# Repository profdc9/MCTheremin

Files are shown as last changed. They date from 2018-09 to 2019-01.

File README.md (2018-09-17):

This is a theremin based on the "Bluepill" devboard with a STM32F103C8T6 microcontroller.
This material is copyrighted by Daniel Marks (KW4TI) and licensed under
the Creative Commons License CC-BY-SA 4.0.  Software is copyrighted using the zlib
open-source license.

It consists of three parts: 

MCTheremin directory - the stm32duino project

board - the PCB board in Kicad of the theremin.

genwaves - little octave script to generate the waveform data

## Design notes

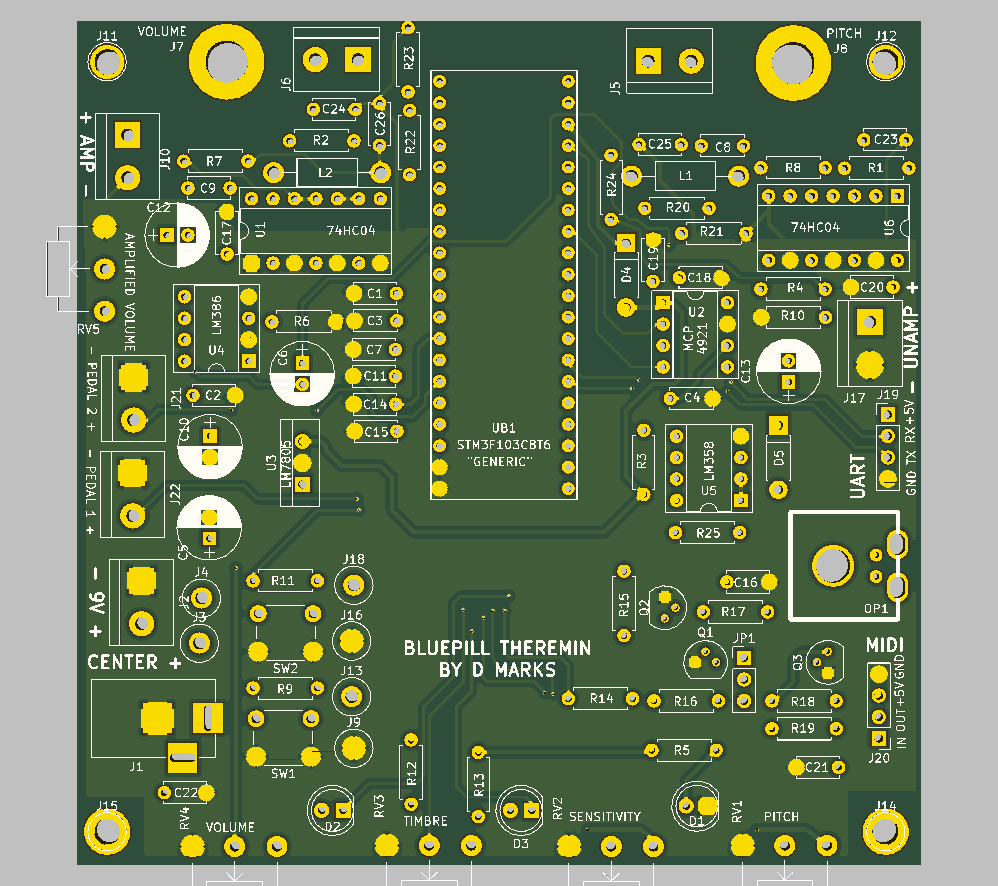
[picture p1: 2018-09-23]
board/MCTheremin.png

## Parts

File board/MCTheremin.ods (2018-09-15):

 | MCTheremin BOM
 | 86
C1 | 100 nF ceramic disc capacitor
C2 | 100 nF ceramic disc capacitor
C3 | 100 nF ceramic disc capacitor
C4 | 100 nF ceramic disc capacitor
C5 | 100 uF ceramic disc capacitor
C6 | 10 uF radial electrolytic capacitor
C7 | 100 nF ceramic disc capacitor
C8 | 33 pF ceramic disc capacitor
C9 | 68 pF ceramic disc capacitor
C10 | 100 uF radial electrolytic capacitor
C11 | 100 nF ceramic disc capacitor
C12 | 220 uF radial electrolytic capacitor
C13 | 220 uF radial electrolytic capacitor
C14 | 100 nF ceramic disc capacitor
C15 | 100 nF ceramic disc capacitor
C16 | 100 nF ceramic disc capacitor
C17 | 100 nF ceramic disc capacitor
C18 | 100 nF ceramic disc capacitor
C19 | 100 nF ceramic disc capacitor
D1 | 3 mm LED
D2 | 3 mm LED
D3 | 3 mm LED
D4 | 1N5819
D5 | 1N5819
J1 | Barrel_Jack
J2 | 2 position terminal block
J3 | Conn_01x01
J4 | Conn_01x01
J5 | 2 position terminal block
J6 | 2 position terminal block
J7 | Conn_01x01
J8 | Conn_01x01
J9 | Conn_01x01
J10 | 2 position terminal block
J11 | Conn_01x01
J12 | Conn_01x01
J13 | Conn_01x01
J14 | Conn_01x01
J15 | Conn_01x01
J16 | Conn_01x01
J17 | 2 position terminal block
J18 | Conn_01x01
J19 | 4 pin 2.54 mm spacing header
J20 | 4 pin 2.54 mm spacing header
J21 | 2 position terminal block
J22 | 2 position terminal block
JP1 | 3 pin 2.54 mm spacing header
OP1 | IFE97
Q1 | 2N3904
Q2 | 2N3904
Q3 | 2N3904
R1 | 10k ¼ watt resistor
R2 | 10k ¼ watt resistor
R3 | 100k ¼ watt resistor
R5 | 1k ¼ watt resistor
R6 | 10k ¼ watt resistor
R7 | 10k ¼ watt resistor
R8 | 10k ¼ watt resistor
R9 | 10k ¼ watt resistor
R10 | 10k ¼ watt resistor
R11 | 10k ¼ watt resistor
R12 | 1k ¼ watt resistor
R13 | 1k ¼ watt resistor
R14 | 1k ¼ watt resistor
R15 | 1k ¼ watt resistor
R16 | 10k ¼ watt resistor
R17 | 100R ¼ watt resistor
R18 | 220R ¼ watt resistor
R19 | 220R ¼ watt resistor
R20 | 1k ¼ watt resistor
R21 | 1.8k ¼ watt resistor
R22 | 1k ¼ watt resistor
R23 | 1.8k ¼ watt resistor
RV1 | 10k ¼ watt resistor
RV2 | 10k ¼ watt resistor
RV3 | 10k ¼ watt resistor
RV4 | 10k ¼ watt resistor
RV5 | 10k ¼ watt resistor
SW1 | 6 mm PCB pushbutton normally open
SW2 | 6 mm PCB pushbutton normally open
U1 | 74HC04 DIP-14 package
U2 | MCP4921 DIP-8 package
U3 | LM7805 TO-220
U4 | LM386 DIP-8 package
U5 | LM358 DIP-8 package
UB1 | BLUEPILL STM32F103C8T6 board (two header sockets)

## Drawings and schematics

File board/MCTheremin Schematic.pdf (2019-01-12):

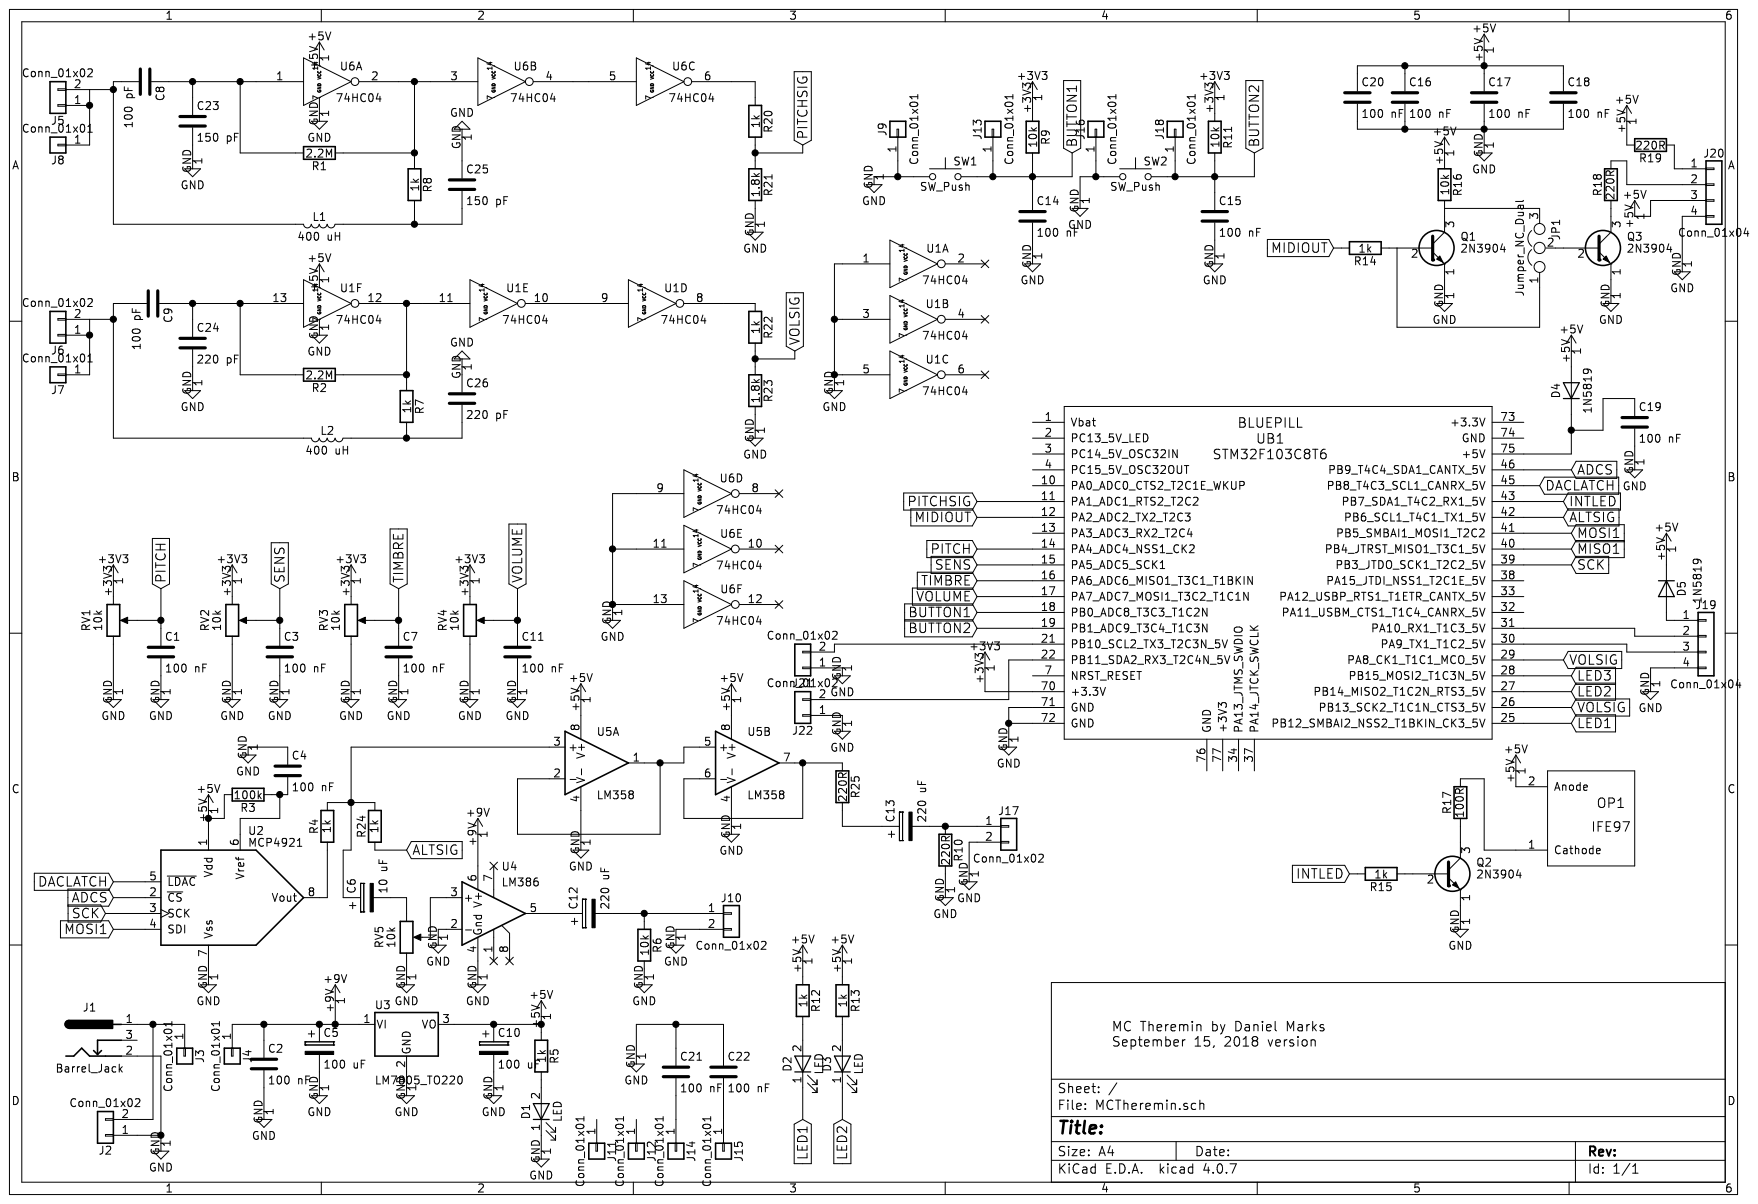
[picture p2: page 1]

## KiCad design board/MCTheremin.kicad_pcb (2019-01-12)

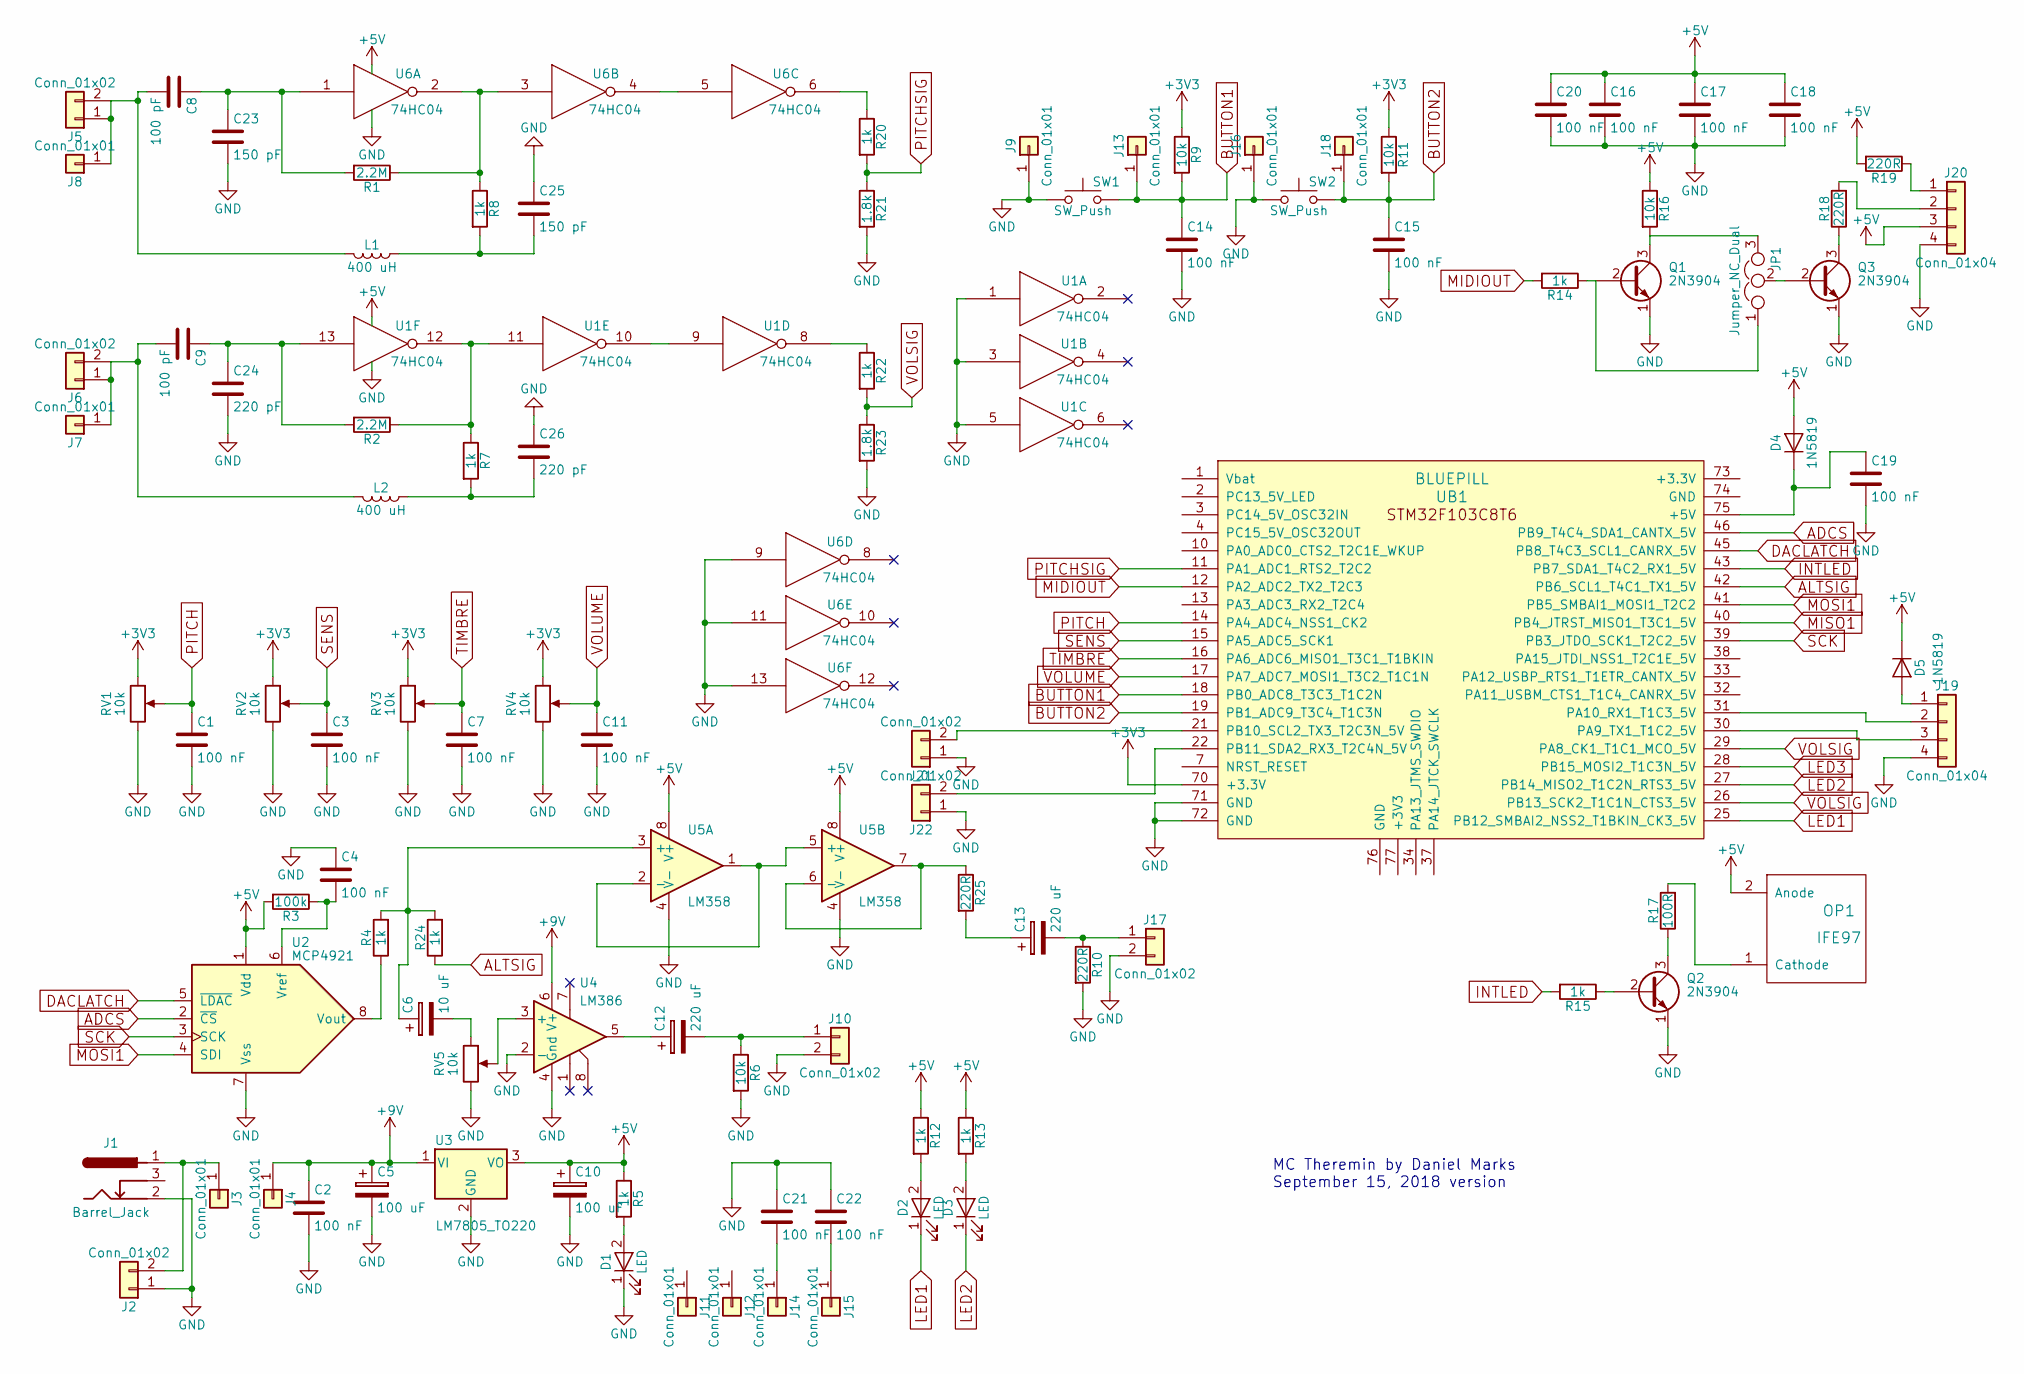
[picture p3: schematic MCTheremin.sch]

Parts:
C1, C2, C3, C4, C7, C11, C14, C15, C16, C17, C18, C19, C20, C21, C22: 100 nF; C_Disc_D5.0mm_W2.5mm_P5.00mm
C5, C10: 100 uF; CP_Radial_D7.5mm_P2.50mm
C6: 10 uF; CP_Radial_D7.5mm_P2.50mm
C8, C9: 100 pF; C_Disc_D5.0mm_W2.5mm_P5.00mm
C12, C13: 220 uF; CP_Radial_D7.5mm_P2.50mm
C23, C25: 150 pF; C_Disc_D5.0mm_W2.5mm_P5.00mm
C24, C26: 220 pF; C_Disc_D5.0mm_W2.5mm_P5.00mm
D1, D2, D3: LED; LED_D5.0mm
D4, D5: 1N5819; D_DO-41_SOD81_P7.62mm_Horizontal
J1: Barrel_Jack; BARREL_JACK
J2, J5, J6, J10, J17, J21, J22: Conn_01x02; TerminalBlock_bornier-2_P5.08mm
J3, J4, J7, J8, J9, J11, J12, J13, J14, J15, J16, J18: Conn_01x01; 1pin
J19, J20: Conn_01x04; Pin_Header_Straight_1x04_Pitch2.54mm
JP1: Jumper_NC_Dual; Pin_Header_Straight_1x03_Pitch2.54mm
L1, L2: 400 uH; L_Axial_L7.0mm_D3.3mm_P12.70mm_Horizontal_Fastron_MICC
OP1: IFE97
Q1, Q2, Q3: 2N3904; TO-92_Molded_Narrow
R1, R2: 2.2M; R_Axial_DIN0207_L6.3mm_D2.5mm_P7.62mm_Horizontal
R3: 100k; R_Axial_DIN0207_L6.3mm_D2.5mm_P7.62mm_Horizontal
R4, R5, R7, R8, R12, R13, R14, R15, R20, R22, R24: 1k; R_Axial_DIN0207_L6.3mm_D2.5mm_P7.62mm_Horizontal
R6, R9, R11, R16: 10k; R_Axial_DIN0207_L6.3mm_D2.5mm_P7.62mm_Horizontal
R10, R18, R19, R25: 220R; R_Axial_DIN0207_L6.3mm_D2.5mm_P7.62mm_Horizontal
R17: 100R; R_Axial_DIN0207_L6.3mm_D2.5mm_P7.62mm_Horizontal
R21, R23: 1.8k; R_Axial_DIN0207_L6.3mm_D2.5mm_P7.62mm_Horizontal
RV1, RV2, RV3, RV4, RV5: 10k; Potentiometer_WirePads
SW1, SW2: SW_Push; SW_PUSH_6mm_h4.3mm
U1, U6: 74HC04; DIP-14_W7.62mm_Socket
U2: MCP4921; DIP-8_W7.62mm_Socket
U3: LM7805_TO220; TO-220-3_Vertical
U4: LM386; DIP-8_W7.62mm_Socket
U5: LM358; DIP-8_W7.62mm_Socket
UB1: BLUEPILL

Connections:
+3V3: R9.1, R11.1, RV1.1, RV2.1, RV3.1, RV4.1, UB1.70 (+3.3V)
+5V: C10.1, C16.1, C17.1, C18.1, C20.1, D4.2 (A), D5.1 (K), J20.3, OP1.2 (Anode), R3.2, R5.1, R12.1, R13.1, R16.1, R19.2, U1.14 (VCC), U2.1 (Vdd), U3.3 (VO), U5.8 (V+), U6.14 (VCC)
+9V: C2.1, C5.1, J4.1, U3.1 (VI), U4.6 (V+)
ADCS: U2.2 (~CS), UB1.46 (PB9_T4C4_SDA1_CANTX_5V)
ALTSIG: R24.1, UB1.42 (PB6_SCL1_T4C1_TX1_5V)
BUTTON1: C14.1, J13.1, R9.2, SW1.2, UB1.18 (PB0_ADC8_T3C3_T1C2N)
BUTTON2: C15.1, J18.1, R11.2, SW2.2, UB1.19 (PB1_ADC9_T3C4_T1C3N)
DACLATCH: U2.5 (~LDAC), UB1.45 (PB8_T4C3_SCL1_CANRX_5V)
GND: C1.2, C2.2, C3.2, C4.1, C5.2, C7.2, C10.2, C11.2, C14.2, C15.2, C16.2, C17.2, C18.2, C19.2, C20.2, C21.1, C22.1, C23.2, C24.2, C25.1, C26.1, D1.1 (K), J1.2, J2.1, J9.1, J10.2, J16.1, J17.2, J19.4, J20.4, J21.1, J22.1, Q1.1 (E), Q2.1 (E), Q3.1 (E), R6.2, R10.2, R21.2, R23.2, RV1.3, RV2.3, RV3.3, RV4.3, RV5.3, SW1.1, SW2.1, U1.1, U1.3, U1.5, U1.7 (GND), U2.7 (Vss), U3.2 (GND), U4.2 (-), U4.4 (Gnd), U5.4 (V-), U6.7 (GND), U6.9, U6.11, U6.13, UB1.71 (GND), UB1.72 (GND)
INTLED: R15.2, UB1.43 (PB7_SDA1_T4C2_RX1_5V)
LED1: D2.1 (K), UB1.25 (PB12_SMBAI2_NSS2_T1BKIN_CK3_5V)
LED2: D3.1 (K), UB1.27 (PB14_MISO2_T1C2N_RTS3_5V)
MIDIOUT: R14.2, UB1.12 (PA2_ADC2_TX2_T2C3)
MOSI1: U2.4 (SDI), UB1.41 (PB5_SMBAI1_MOSI1_T2C2)
unnamed: C4.2, R3.1, U2.6 (Vref)
unnamed: C6.1, R4.2, R24.2, U5.3 (+)
unnamed: C6.2, RV5.1
unnamed: C8.2, J5.1, J5.2, J8.1, L1.2
unnamed: C9.2, J6.1, J6.2, J7.1, L2.2
unnamed: C12.1, U4.5
unnamed: C12.2, J10.1, R6.1
unnamed: C13.1, R25.2
unnamed: C13.2, J17.1, R10.1
unnamed: C19.1, D4.1 (K), UB1.75 (+5V)
unnamed: C21.2, J14.1
unnamed: C22.2, J15.1
unnamed: C8.1, C23.1, R1.2, U6.1
unnamed: C9.1, C24.1, R2.2, U1.13
unnamed: C25.2, L1.1, R8.2
unnamed: C26.2, L2.1, R7.2
unnamed: D1.2 (A), R5.2
unnamed: D2.2 (A), R12.2
unnamed: D3.2 (A), R13.2
unnamed: D5.2 (A), J19.1
unnamed: J1.1, J2.2, J3.1
unnamed: J19.2, UB1.31 (PA10_RX1_T1C3_5V)
unnamed: J19.3, UB1.30 (PA9_TX1_T1C2_5V)
unnamed: J20.1, R19.1
unnamed: J20.2, R18.2
unnamed: J21.2, UB1.21 (PB10_SCL2_TX3_T2C3N_5V)
unnamed: J22.2, UB1.22 (PB11_SDA2_RX3_T2C4N_5V)
unnamed: JP1.1, Q1.2 (B), R14.1
unnamed: JP1.2, Q3.2 (B)
unnamed: JP1.3, Q1.3 (C), R16.2
unnamed: OP1.1 (Cathode), R17.2
unnamed: Q2.2 (B), R15.1
unnamed: Q2.3 (C), R17.1
unnamed: Q3.3 (C), R18.1
unnamed: R1.1, R8.1, U6.2, U6.3
unnamed: R2.1, R7.1, U1.11, U1.12
unnamed: R4.1, U2.8 (Vout)
unnamed: R20.1, U6.6
unnamed: R22.1, U1.8
unnamed: R25.1, U5.6 (-), U5.7
unnamed: RV5.2, U4.3 (+)
unnamed: U1.9, U1.10
unnamed: U5.1, U5.2 (-), U5.5 (+)
unnamed: U6.4, U6.5
PITCH: C1.1, RV1.2, UB1.14 (PA4_ADC4_NSS1_CK2)
PITCHSIG: R20.2, R21.1, UB1.11 (PA1_ADC1_RTS2_T2C2)
SCK: U2.3 (SCK), UB1.39 (PB3_JTDO_SCK1_T2C2_5V)
SENS: C3.1, RV2.2, UB1.15 (PA5_ADC5_SCK1)
TIMBRE: C7.1, RV3.2, UB1.16 (PA6_ADC6_MISO1_T3C1_T1BKIN)
VOLSIG: R22.2, R23.1, UB1.26 (PB13_SCK2_T1C1N_CTS3_5V), UB1.29 (PA8_CK1_T1C1_MCO_5V)
VOLUME: C11.1, RV4.2, UB1.17 (PA7_ADC7_MOSI1_T3C2_T1C1N)

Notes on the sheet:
MC Theremin by Daniel Marks September 15, 2018 version

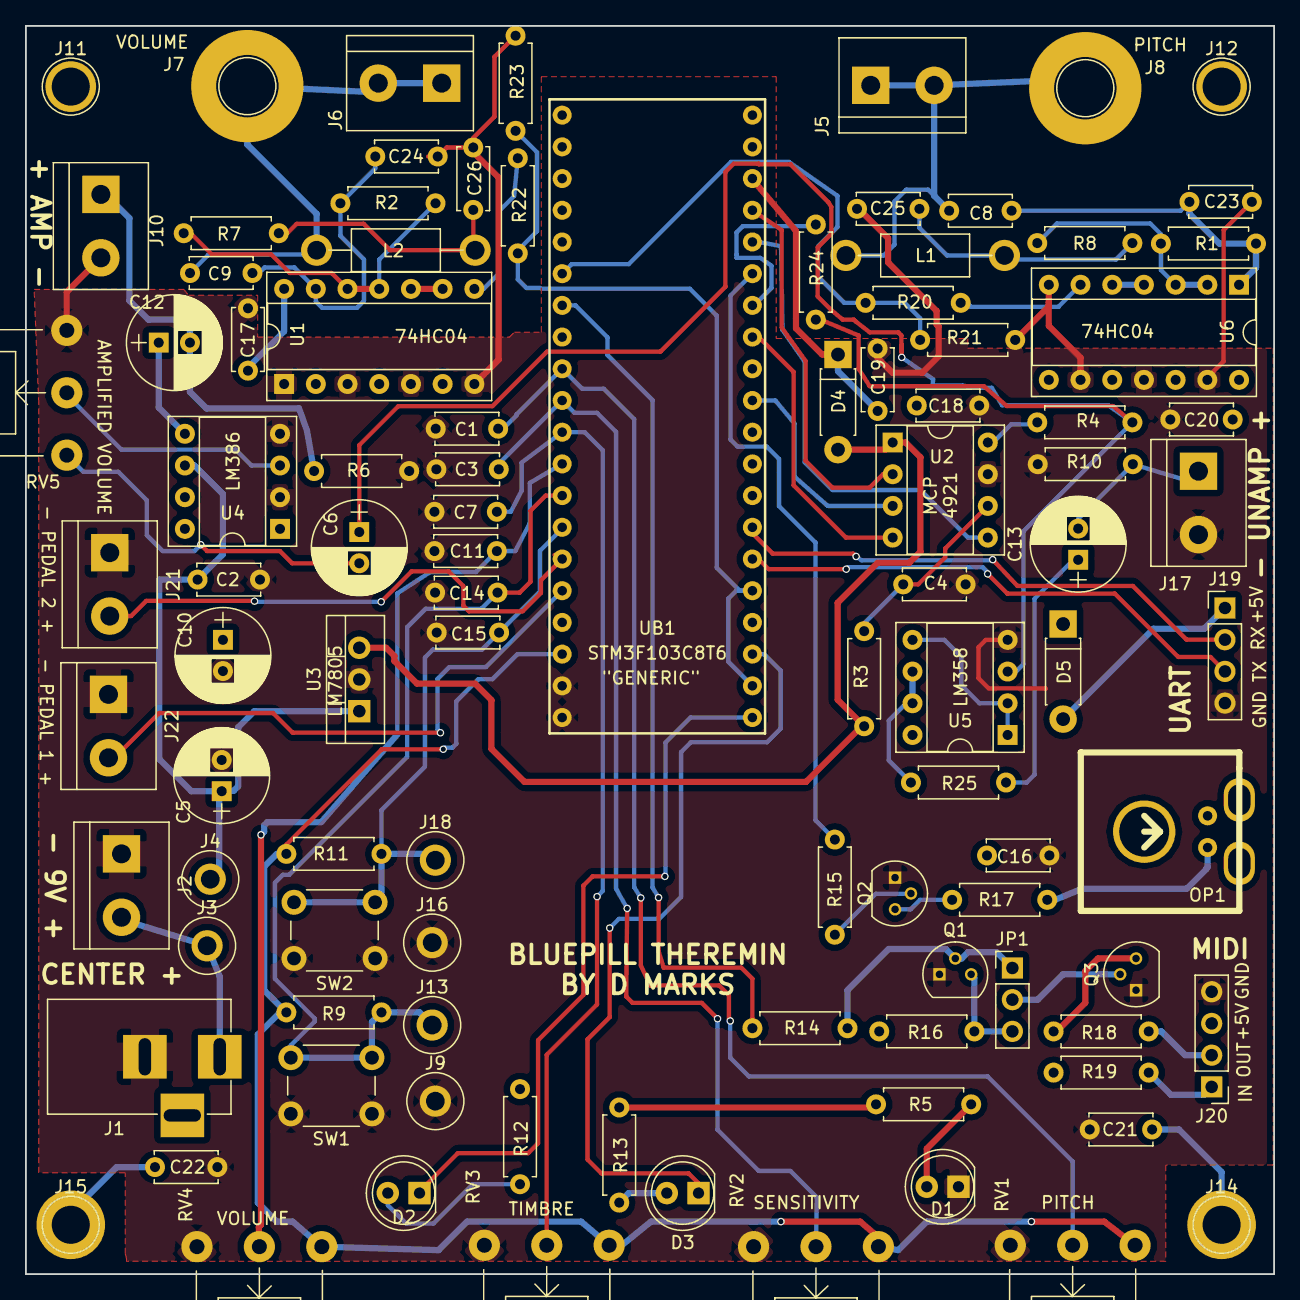
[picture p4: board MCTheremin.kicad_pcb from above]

Board: 2 copper layers, 100.0 x 100.0 mm, 99 parts (0 on the bottom side), 65 nets.

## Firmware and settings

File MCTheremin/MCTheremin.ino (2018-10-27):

/*
 *  Theremin STM32duino project
 */

/*
 * Copyright (c) 2018 Daniel Marks

This software is provided 'as-is', without any express or implied
warranty. In no event will the authors be held liable for any damages
arising from the use of this software.

Permission is granted to anyone to use this software for any purpose,
including commercial applications, and to alter it and redistribute it
freely, subject to the following restrictions:

1. The origin of this software must not be misrepresented; you must not
   claim that you wrote the original software. If you use this software
   in a product, an acknowledgment in the product documentation would be
   appreciated but is not required.
2. Altered source versions must be plainly marked as such, and must not be
   misrepresented as being the original software.
3. This notice may not be removed or altered from any source distribution.
 */

#include "FrequencyCounter.h"
#include "ButtonPanel.h"
#include "MCP4921.h"
#include "debugmsg.h"
#include "EEPROMobjectstore.h"
#include "waves.h"

#define MCTHEREMIN_LED1 PB12
#define MCTHEREMIN_LED2 PB14
#define MCTHEREMIN_INTLED PB7
#define MCTHEREMIN_ALTSIG PB6

#define MCTHEREMIN_PITCHADJ 4
#define MCTHEREMIN_SENSITIVITY 5
#define MCTHEREMIN_TIMBRE 6
#define MCTHEREMIN_VOLUMEADJ 7

#define MCTHEREMIN_CPU_CLOCK_RATE (F_CPU)
#define MCTHEREMIN_SAMPLE_RATE 32000
#define MCTHEREMIN_INITIAL_CLOCKS 16000
#define MCTHEREMIN_WAIT_TICKS 1

#define MCTHEREMIN_WAIT_CYCLES (MCTHEREMIN_CPU_CLOCK_RATE/MCTHEREMIN_SAMPLE_RATE)

#define DEMCR           (*((volatile uint32_t *)0xE000EDFC))
#define DWT_CTRL        (*(volatile uint32_t *)0xe0001000)
#define CYCCNTENA       (1<<0)
#define DWT_CYCCNT      ((volatile uint32_t *)0xE0001004)
#define CPU_CYCLES      *DWT_CYCCNT
#define DEMCR_TRCENA    0x01000000

int skipsamples;
int volumelevel;
int cursample;
unsigned int volume;
const unsigned short *curtone = sinewave;
bool extrasounds = false;

unsigned int avgvolumecount;
unsigned int avgpitchcount;
int pitchscalefactor = 2048;
int volscalefactor = 10;

static void initialize_cortex_m3_cycle_counter(void)
{
  DEMCR |= DEMCR_TRCENA; 
  *DWT_CYCCNT = 0; 
  DWT_CTRL |= CYCCNTENA;
}

void readInterrupt(void);
 
HardwareTimer timeb(3);

void setup_timer(unsigned short checkInterval, unsigned short prescaleFactor)
{
  timeb.pause();
  timeb.setCount(0);
  timeb.setPrescaleFactor(prescaleFactor);
  timeb.setOverflow(checkInterval);
  timeb.setCompare(TIMER_CH1, 1);
  timeb.attachCompare1Interrupt(readInterrupt);
  timeb.refresh();
  timeb.resume();  
}

FrequencyCounter freqCounter(2000);
const byte button_list[4] = {PB0,PB1,PB10,PB11};
ButtonPanel buttonPanel(4,button_list,10,10);
MCP4921 mcp4921;

void setup_controls(void)
{
  pinMode(MCTHEREMIN_ALTSIG,INPUT);
  pinMode(MCTHEREMIN_LED1,OUTPUT);
  digitalWrite(MCTHEREMIN_LED1,HIGH);
  pinMode(MCTHEREMIN_LED2,OUTPUT);
  digitalWrite(MCTHEREMIN_LED2,HIGH);
  pinMode(MCTHEREMIN_INTLED,OUTPUT);
  digitalWrite(MCTHEREMIN_INTLED,HIGH);
  pinMode(MCTHEREMIN_PITCHADJ,INPUT_ANALOG);
  pinMode(MCTHEREMIN_TIMBRE,INPUT_ANALOG);
  pinMode(MCTHEREMIN_SENSITIVITY,INPUT_ANALOG);
  pinMode(MCTHEREMIN_VOLUMEADJ,INPUT_ANALOG);
}

void setup() {
   afio_cfg_debug_ports(AFIO_DEBUG_SW_ONLY); // release PB3 and PB5 
//   disableDebugPorts();
   initialize_cortex_m3_cycle_counter();
  // default debug messages off if on UART1 (might need it for rig)
#ifdef SERIAL_USB
  setDebugMsgMode(1);
#else
  setDebugMsgMode(0);
#endif
   mcp4921.setup();
   freqCounter.setup();
   Serial.begin(115200); // Ignored by Maple. But needed by boards using Hardware serial via a USB to Serial Adaptor
   buttonPanel.setup();
   EEPROMstore.setup(2);
   //EEPROMstore.formatBank(0);
   cursample = 0;
   setup_controls();
   setup_timer(MCTHEREMIN_WAIT_CYCLES,1);
   calibrate();
}

unsigned int initialclocks = 0;
unsigned int lastvolumeval = 0, lastpitchval = 0;
unsigned int volumecountfilter = 0, pitchcountfilter = 0;
volatile unsigned int ticks = 0;
unsigned int lastticks = 0;
int circbufpl = 0;
int analogcircbufpl = 0;
volatile bool soundOn = false;

#define CIRCBUFFERLEN 1024

unsigned short pitchsamples[CIRCBUFFERLEN];
unsigned short volumesamples[CIRCBUFFERLEN];
unsigned short pitchknobsamples[CIRCBUFFERLEN];
unsigned short volumeknobsamples[CIRCBUFFERLEN];

void reseteverything(void)
{
  initialclocks = 0;
  circbufpl = 0;
  analogcircbufpl = 0;
  cursample = 0;
  ticks = 0;
  for (int i=0;i<CIRCBUFFERLEN;i++) 
  {
    pitchsamples[i] = 0;
    pitchknobsamples[i] = 0;
    volumesamples[i] = 0;
    volumeknobsamples[i] = 0;
  }
}

 void calculatecounts(void)
 {
  pitchcountfilter = 0;
  volumecountfilter = 0;
  pitchscalefactor = 0;
  volscalefactor = 0;
  for (int i=0;i<CIRCBUFFERLEN;i++)
  {
     pitchcountfilter += pitchsamples[i];
     volumecountfilter += volumesamples[i];
     pitchscalefactor += pitchknobsamples[i];
     volscalefactor += volumeknobsamples[i];
  }
 }

 void readInterrupt(void) 
 {
  unsigned int volumeval, pitchval;
  ticks++;
  freqCounter.readUpdate(volumeval,pitchval);
  if (initialclocks < MCTHEREMIN_INITIAL_CLOCKS)
      initialclocks++;
  else
  {
      if (soundOn)
      {
          cursample += skipsamples;
          cursample &= 0xFFFFF;
          mcp4921.sendSample((curtone[cursample >> 8] * volumelevel) >> 8);
      }
  }
  circbufpl++;
  if (circbufpl >= CIRCBUFFERLEN)
      circbufpl = 0;
  pitchsamples[circbufpl] = (pitchval - lastpitchval) & 0xFFFF;
  lastpitchval = pitchval;
  volumesamples[circbufpl] = (volumeval - lastvolumeval) & 0xFFFF;
  lastvolumeval = volumeval;
  buttonPanel.pollButtons(); 
}

void getanalogcntrls(void)
{
  analogcircbufpl++;
  if (analogcircbufpl >= CIRCBUFFERLEN)
      analogcircbufpl = 0;
  pitchknobsamples[analogcircbufpl] = analogRead(MCTHEREMIN_PITCHADJ);
  volumeknobsamples[analogcircbufpl] = analogRead(MCTHEREMIN_VOLUMEADJ); 
}

void calibrate(void)
{
  soundOn = false;
  for (int i=0;i<2;i++)
  {
    digitalWrite(MCTHEREMIN_LED1,LOW);
    if (extrasounds) mcp4921.tone(523,500);
      else delay(500);
    digitalWrite(MCTHEREMIN_LED1,HIGH);
    if (extrasounds) mcp4921.tone(392,1000);
      else delay(500);
  }
  reseteverything();
  while (ticks < 50000)
    digitalWrite(MCTHEREMIN_LED1,(ticks & 0x400) ? HIGH : LOW);
  calculatecounts();
  avgvolumecount = volumecountfilter;
  avgpitchcount = pitchcountfilter;
  digitalWrite(MCTHEREMIN_LED1,LOW);
  if (extrasounds) mcp4921.tone(392,500);
    else delay(500);
  digitalWrite(MCTHEREMIN_LED1,HIGH);  
  //reseteverything();
  soundOn = true;
}

void loop() {
  static int ledticks = 0;
  digitalWrite(MCTHEREMIN_LED2,((++ledticks) & 0x400) != 0? LOW : HIGH);

  while (lastticks == ticks) {};

  getanalogcntrls();

  calculatecounts();
  volumelevel = avgvolumecount - volumecountfilter;
  volscalefactor = volscalefactor*35/(4096*CIRCBUFFERLEN);
  if (volumelevel < 0)
      volumelevel = 0xFF;
  else
  {
      volumelevel = 0xFF - volumelevel * volscalefactor / 16;
      if (volumelevel < 0) volumelevel = 0;
  }
  pitchscalefactor /= CIRCBUFFERLEN;
  skipsamples = (avgpitchcount - pitchcountfilter) * pitchscalefactor;
  if (skipsamples < 8192)
    skipsamples = 0;
  else
    skipsamples = skipsamples / 4;
  if (buttonPanel.getButtonState(0))
     calibrate(); 
  curtone = wavelist[(analogRead(MCTHEREMIN_TIMBRE)*WAVE_NUM)/4096];
   /*{
     static int updat =0;
     updat++;
     if (updat > 2000)
     {
      updat = 0;
      DEBUGMSG("pitchscalefactor = %u volscalefactor=%u",pitchscalefactor,volscalefactor);
      DEBUGMSG("skipsamples=%u pitchcountfilter=%u volumecountfilter=%u",skipsamples,pitchcountfilter,volumecountfilter);
      DEBUGMSG("avgpitchcount=%u avgvolumecount=%u volumelevel=%u",avgpitchcount,avgvolumecount,volumelevel);
     }
  } */
}

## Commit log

2018-09-17 Pre LC
    [MCTheremin-B.Cu.gbr, MCTheremin-B.Mask.gbr, MCTheremin-B.SilkS.gbr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]
2018-09-23 Changed to LC oscillator - removed copper fill from under oscillator
    [MCTheremin-B.Cu.gbr, MCTheremin-B.Mask.gbr, MCTheremin-B.SilkS.gbr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]
2018-10-07 First working MCTheremin with LC oscillators
    [MCTheremin.sch]
2019-01-12 Accidental connection in LM358
    [MCTheremin-B.Cu.gbr, MCTheremin-B.Mask.gbr, MCTheremin-B.SilkS.gbr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]
